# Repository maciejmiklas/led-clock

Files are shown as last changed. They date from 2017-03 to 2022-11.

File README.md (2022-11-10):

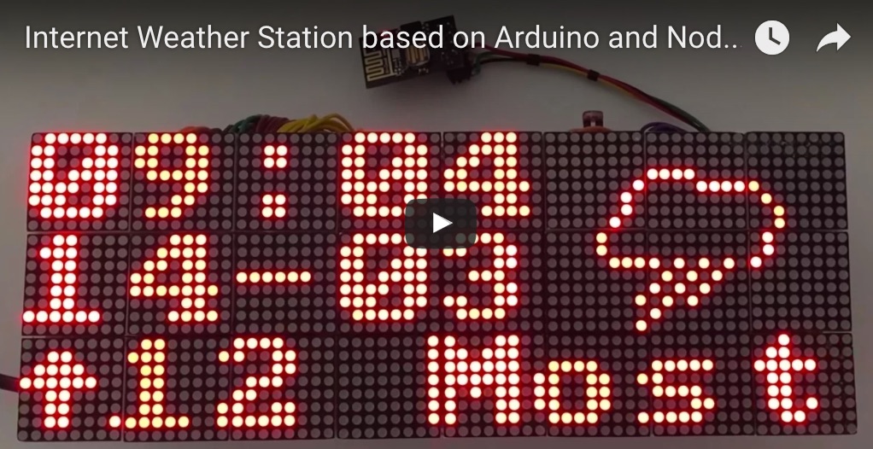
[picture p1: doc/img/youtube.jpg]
Click me to play video :) (https://www.youtube.com/watch/xcpKJU7HzQs)


[This video shows a boxed version with the latest improvements](https://www.youtube.com/watch?v=c8wJdQJHX8o)

It is a weather station with a three-day forecast, current temperature, and a clock with local time and date.

The project is based on Arduino, NodeMCU provides access to the Internet over WiFi. 
The display is built from single LEDs. Since they can be bright, it adopts illumination based on light conditions.
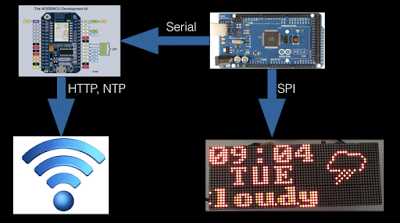
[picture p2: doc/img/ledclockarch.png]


Let's start from the beginning ;)

I've found those 8x8 LED modules:

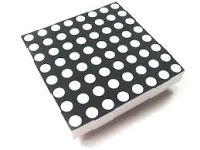
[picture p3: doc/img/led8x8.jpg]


so I've decided to combine a few to build a display. In my case, there are three lines, each consisting of 8 modules, 24 in total; this gives us 1532 single LEDs! 

To drive a single module, I've chosen MAX72xx. I also wanted to improve my soldering skills, so I've decided to go for 24 PIN DIP chips and solder them to prototype boards:

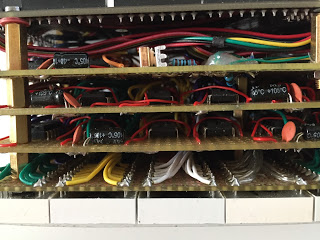
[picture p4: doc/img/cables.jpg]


That worked out well regarding those skills, but I recommend using LED modules combined with MAX Chip. It will save you at least a few hours, not to mention the time spent afterward when a single cable gets loose ;) Such a combo module has only three wires instead of 16.

So we have a hardware part for our display: 24 led modules with drivers. Now it's time to light them up! I've decided to go for Arduino Mega because it has two serial ports, so it's easier to debug things (one port will be used for communication with EPS8266). You could also use Uno. In this case, you would have to daisy chain MAX chips and change the software address because Uno does not have enough output pins.

I was looking for an API that will join all led modules into one canvas so that you can print spites without bothering with transitions between LED modules. I did not find anything that would make me happy, so I've decided to implement  [one by myself](https://github.com/maciejmiklas/LEDDisplay). It provides a simple canvas with fonts and a few animations, which is everything necessary to display time and weather.

We have a display and API to control it. Now we need to get the date and weather. Arduino does not support Internet connectivity, and it does not have enough resources to process incoming data. So I've decided to use NodeMCU. With a few Lua scripts, I could implement [simple API](https://github.com/maciejmiklas/NodeMCUUtils) accessible over a serial port. Arduino connects over it with NodeMCU, obtains time, date, and weather, and displays it.

To provide a date, the NodeMCU connects with the NTP server and receives time in UTC. Afterward, it calculates the local date from it. I could use one of the Internet services to grab the local time, but I was looking for a solution that would remain stable for a long time. Those services can change their API or go offline, but the NTP protocol is solid. In the worse case, you will have to change a server name. The current implementation also supports failover through many different servers, so you will probably not have to bother with it soon ;)

Getting the weather was tricky because I had to find an API that would return a response small enough so NodeMCU could parse it. I've decided to use yahoo weather. They provide a nice REST API with a small and straightforward response. Hopefully, they will keep interfaces stable for a long time.

# Putting things together
First, you must build the display described in this project: https://github.com/maciejmiklas/LEDDisplay . You can use the same PINs on Mega so that you will not have to alter the software.

After the display is ready, you should connect ESP8266 and the photo resistor. The Schematic below contains all hardware elements together:

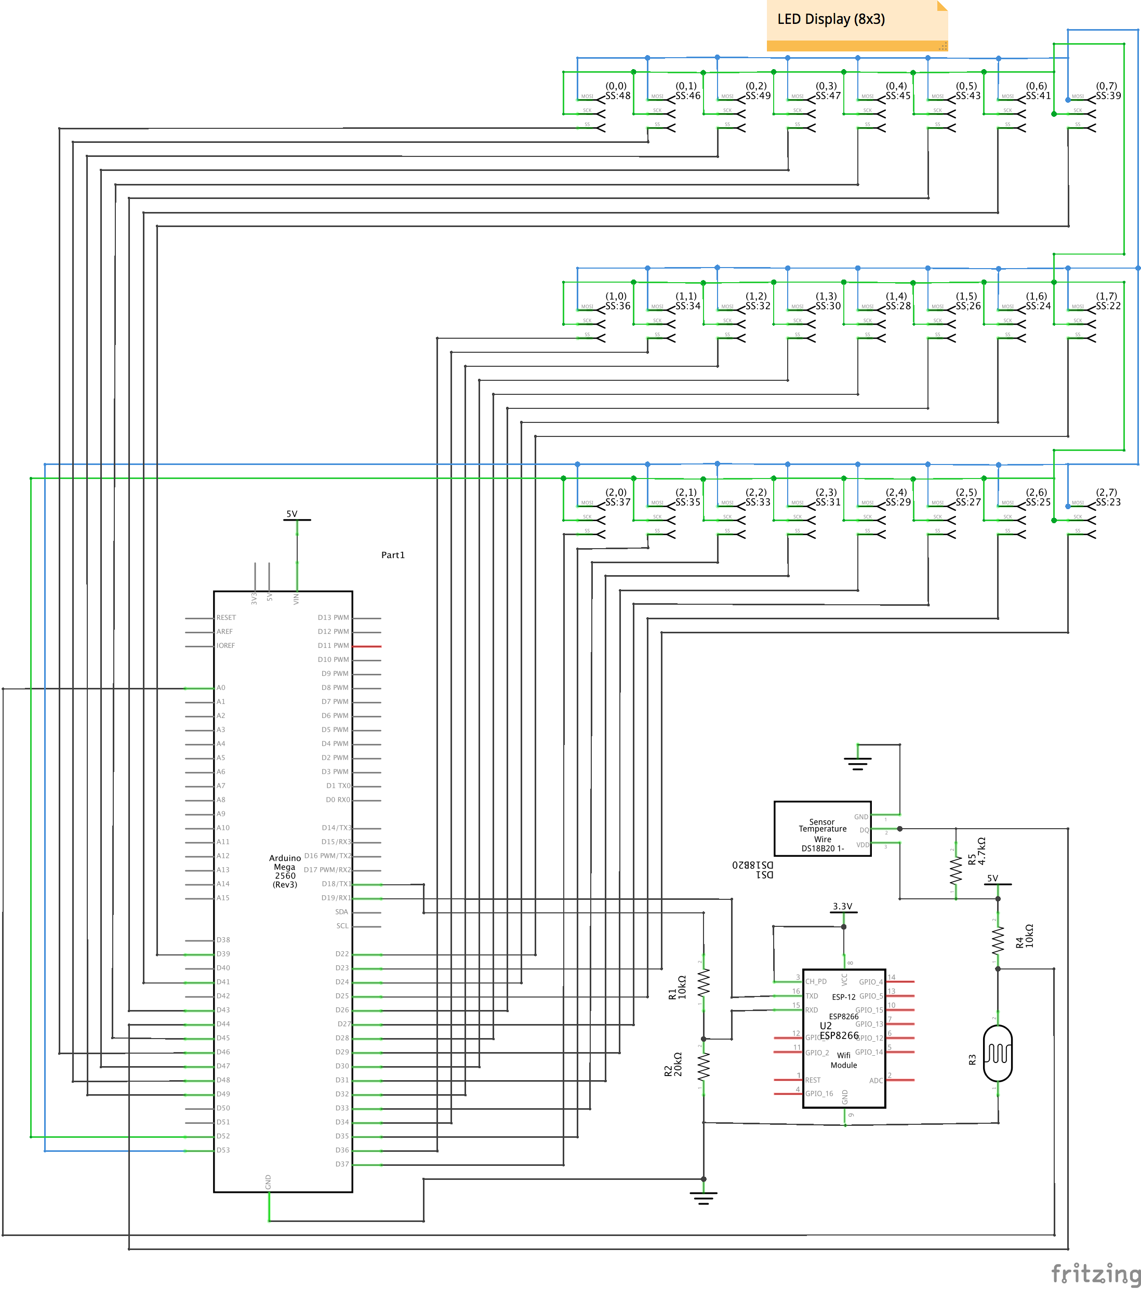
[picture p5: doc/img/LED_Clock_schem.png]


# Software for Arduino Mega
This project (LEDClock) contains the main software part,  you have to compile it and upload it to Arduino. Compilation requires an SPI module and two other libraries: https://github.com/maciejmiklas/LEDDisplay and https://github.com/maciejmiklas/ArdLog

In [this blog post](http://maciej-miklas.blogspot.com/2017/03/weather-station-based-on-arduino-and.html#sloeber) instructions on how to compile it using Sloeber.

# Software for NodeMCU/ESP32
To provide weather and time to Arduino, you will have to clone this project: https://github.com/maciejmiklas/NodeMCUUtils , modify a few scripts, and upload those afterward into NodeMCU. Here are the steps:

1. Compile firmware for NodeMCU/ESP32 so that it has all required modules: file, mqtt, gpio, net, node, tmr, uart, WiFi, sjson. There is also already a precompiled version in the repo.

2. Edit *serial_api_clock.lua* and set UTC to offset for your location. It will be required to calculate local time from UTC. For most European countries, it's already set to the correct value. For US you will have to replace *require "date_format_europe"* with *require "date_format_america"* in _*init.lua_

3. Register at [Open Weather](https://openweathermap.org) to get the application id. You will have to provide it in the next step.

4. Create a new file called: *credentials.lua* and specify login data for WiFi connection. It's just one line, for example: 
```lua
cred = {ssid = 'openwifi', password = '123456789'}
owe.appid = 'your app id'
```

6. Upload all Lua scripts from _/src_ and _/scr/init_ into NodeMCU.

# Matching LIB versions
* [LED Clock](https://github.com/maciejmiklas/LEDClock) - v1.x.x
* [LED Display](https://github.com/maciejmiklas/LEDDisplay) - v2.x.x
* [Arduino Logger](https://github.com/maciejmiklas/ArdLog) - v2.x.x
* [NodeMCU weather and clock](https://github.com/maciejmiklas/NodeMCUUtils) - v2.x.x
Replace x with the latest version, and they are all compatible.

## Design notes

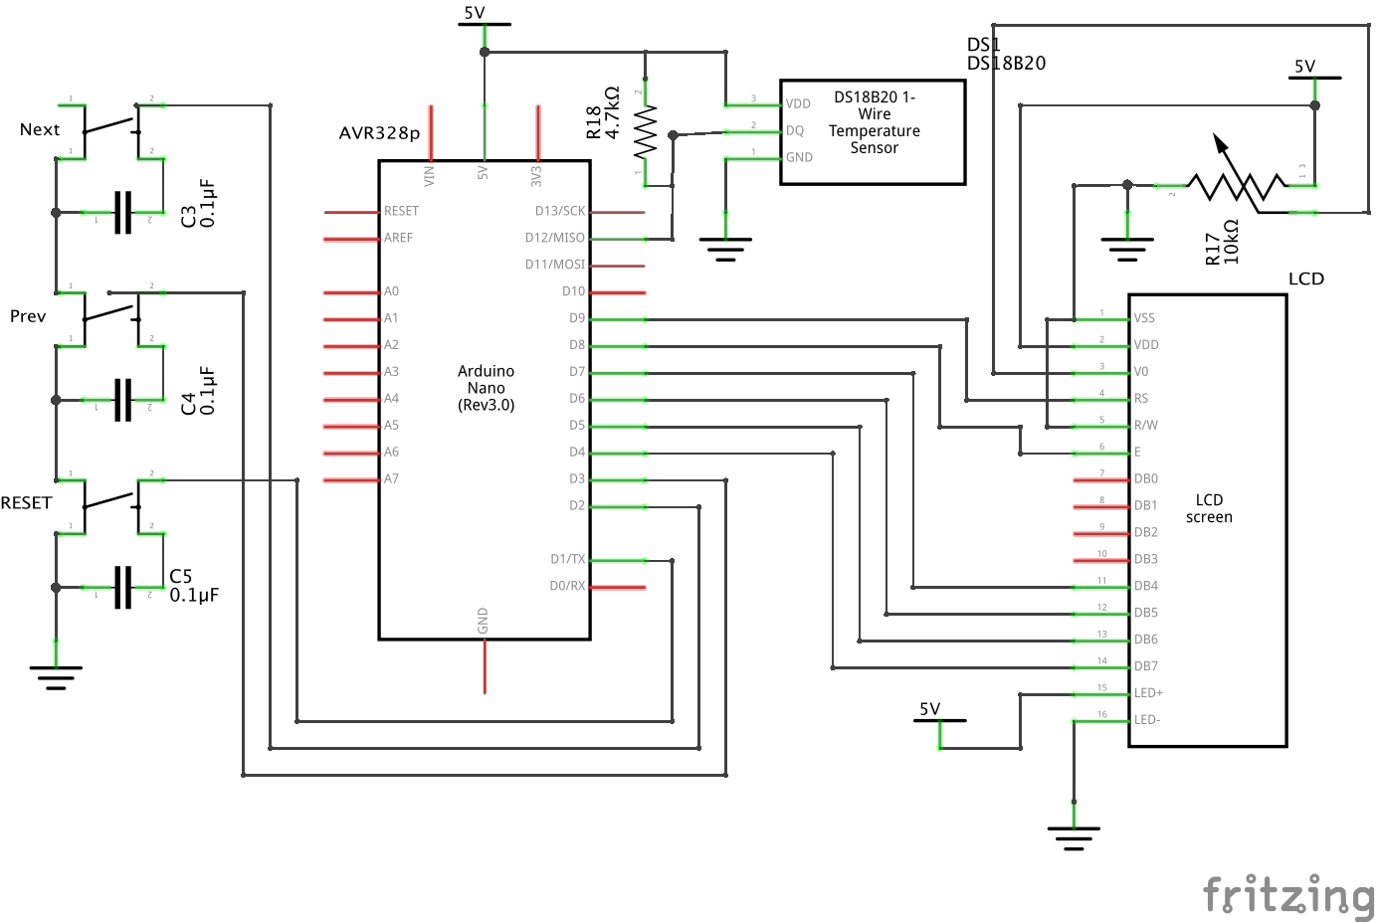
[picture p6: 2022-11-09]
doc/fritzing/Thermostat_schem.png

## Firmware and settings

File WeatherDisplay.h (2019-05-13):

/*
 * Licensed to the Apache Software Foundation (ASF) under one or more
 * contributor license agreements.  See the NOTICE file distributed with
 * this work for additional information regarding copyright ownership.
 * The ASF licenses this file to You under the Apache License, Version 2.0
 * (the "License"); you may not use this file except in compliance with
 * the License.  You may obtain a copy of the License at
 *
 *      http://www.apache.org/licenses/LICENSE-2.0
 *
 * Unless required by applicable law or agreed to in writing, software
 * distributed under the License is distributed on an "AS IS" BASIS,
 * WITHOUT WARRANTIES OR CONDITIONS OF ANY KIND, either express or implied.
 * See the License for the specific language governing permissions and
 * limitations under the License.
 */
#ifndef WEATHERDISPLAY_H_
#define WEATHERDISPLAY_H_

#include "Canvas.h"
#include "SerialAPI.h"
#include "DispUtil.h"
#include "ScrollingText8x8.h"

const static uint8_t WEATHER_ICON_DISPLAYS = 6;
const static uint8_t WEATHER_ICONS = 11;
const static uint8_t WEATHER_ICON_SIZE = WEATHER_ICON_DISPLAYS * WEATHER_ICONS;

class WeatherDisplay {
public:
	WeatherDisplay(Canvas *canvas, SerialAPI *serialAPI);
	virtual ~WeatherDisplay();
	void cycle();
	void init();
	ScrollingText8x8 weatherTextArea;
private:
	const static uint8_t ICON_IDX_MIX_SUN_RAIN = 0;
	const static uint8_t ICON_IDX_PARTLY_SUNNY = 6;
	const static uint8_t ICON_IDX_RAIN = 12;
	const static uint8_t ICON_IDX_THUNDERSTORM = 18;
	const static uint8_t ICON_IDX_MIX_SUN_THUNDERSTORM = 24;
	const static uint8_t ICON_IDX_MOON = 30;
	const static uint8_t ICON_EMPTY = 36;
	const static uint8_t ICON_IDX_MIX_SUN_SNOW = 42;
	const static uint8_t ICON_IDX_SNOW = 48;
	const static uint8_t ICON_IDX_CLOUDY = 54;
	const static uint8_t ICON_IDX_SUNNY = 60;

	const static uint32_t WEATHER_REFRESH_MS = 60000; // 60000 every minute
	const static uint32_t WEATHER_REFRESH_ON_ERROR_MS = 10000; // 10000 every 10 seconds
	const static uint8_t TEXT_WIDTH_PX = 64;
	const static uint8_t TEXT_ANIMATE_DELAY_MS = 20;
	const static uint8_t TEXT_BUFFER_SIZE = 255;
	const static uint8_t TEXT_BUFFER_MAX_SIZE = TEXT_BUFFER_SIZE - 10;
	const static uint8_t ICON_BYTE_WIDTH = 3;
	const static uint8_t ICON_ROWS = 2;
	const static uint8_t ICON_ROW_BYTES = 3;
	const static uint8_t ICON_BYTES = ICON_ROWS * ICON_ROW_BYTES;
	const static uint8_t ICON_HEIGHT_PX = 16;
	const static uint8_t ICON_WIDTH_PX = 24;
	const static uint8_t ICON_START_X_PX = 40;
	const static uint8_t ICON_START_Y_PX = 0;
	const static uint8_t CODES_SIZE = 5;
	const static uint16_t CODES_REFRESH_MS = 1000;
	const static uint8_t CODES_PAUSE_CYCLES = 2;

	Canvas* const canvas;
	SerialAPI* const serialAPI;
	uint32_t lastWeatherRefreshMs;
	uint16_t weatherRefreshMs;
	char buf[TEXT_BUFFER_SIZE];
	uint8_t** const iconData;
	uint8_t lastIcon;

	uint8_t codes[CODES_SIZE];
	uint8_t codesReadSize;
	uint8_t codesIxd;
	uint32_t codesLastRefreshMs;

	void refreshWeatherText(boolean force);
	void refreshIcon();
	void refreshCodes();
	uint8_t inline sep(uint8_t idx, uint8_t chars);
	void inline copyIconData(uint8_t iconIdx);
	void inline refreshWeather();

};

#endif /* WEATHERDISPLAY_H_ */

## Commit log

2015-05-23 just starting
    [LED Matrix SPI.fzz, LEDClock-Driver.fzz, LEDClock.fzz]
2015-05-24 spi led demo
    [LED Matrix SPI.fzz]
2015-05-26 do not remember...
    [LED Matrix SPI.fzz]
2015-05-29 logger util sprites with font
    [LED Matrix SPI.fzz]
2015-05-29 printing font
2015-09-28 switched to real hardware
2015-11-16 connected display 3x8
    [LED Matrix SPI.fzz, LEDClock-Driver.fzz]
2016-09-21 project setup is correct
    [WeatherDisplay.h]
2017-09-15 show current temp
2017-10-01 serial communication stability, display current temp
2017-10-11 temp sensor
2017-10-18 show in/out temp, show ESP status only in case of error
2017-10-19 schama update
    [LED_Clock.fzz]
2019-01-14 DNS error does not break weather
    [WeatherDisplay.h]
2019-04-08 move to ESP32
2019-04-10 adopt to new ESP32 API
